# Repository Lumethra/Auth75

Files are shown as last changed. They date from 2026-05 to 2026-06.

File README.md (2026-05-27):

# Auth 75

## What is this? 

This is a 75% keyboard with a fingerprint sensor. What? A fingerprint sensor in a keyboard? Yes, you've heard it right! This keyboard includes a working fingerprint sensor. But how does it work? Aren't fingerprint sensors tied to motherboards? Continue reading, to get an answer to this question. 

### Features: 
  - Keycool84 layout (modified)
  - Raspberry Pi Pico 2W
    - ZMK (not tested)
    - LiPo battery
    - Battery charger
  - Rotary Encoder Switch (EC11)
  - USB Hub (SL2.1)
    - 1 USB-C upstream
    - 2 USB-C downstreams
    - 1 notched FPC-connector (fingerprint sensor)
    - 1 USB-C to connect to the Pico

---

## Why? 

I always wanted a good keyboard with a working fingerprint sensor, because my password is always too long and I am used to the one on my laptop. Why not just use the one on my laptop? Because I want to close my laptop lid while using a monitor. The second reason is that the one on my laptop doesnt work on Linux, so I wanted to make compatible with my main OS. 

---

## How? 

I did some research and found out that the Framework 13 Fingerprint Reader isnt tied to their motherboard, unlike Lenovo or Dell. I also found a [Framework-Community-Post](https://community.frame.work/t/framework-fingerprint-scanner-for-a-desktop-pc/29845), where the people managed to use the sensor via USB-C. They also found out that the D+ and D- pins are inverted. A huge thank you to these guys. After buying the sensor and testing its functionalty at home, I decided on using a USB-Hub to have the fingerprint reader and the keyboard MCU in on connector. Frameworks support also helped me out with the fingerprint sensor datasheet. And now I've got a 75% keyboard with a working fingerprint sensor. 

---

## Renders

| PCB with Components | 
| --- |
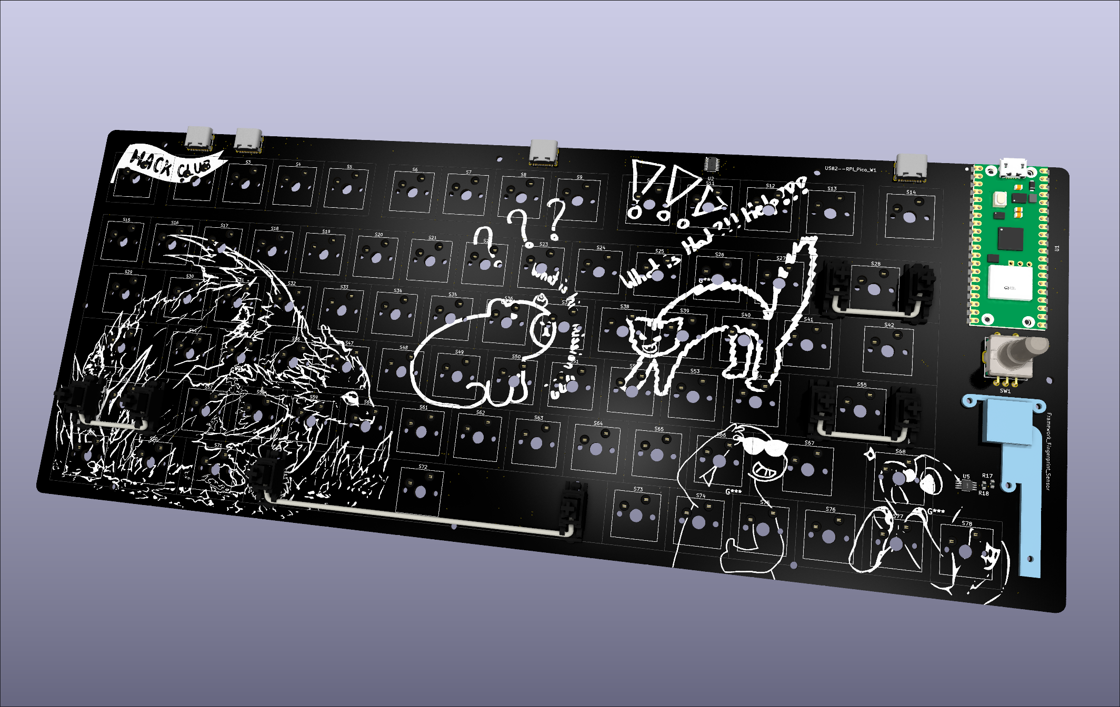
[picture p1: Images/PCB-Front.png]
Auth75 Front with Components
|  |
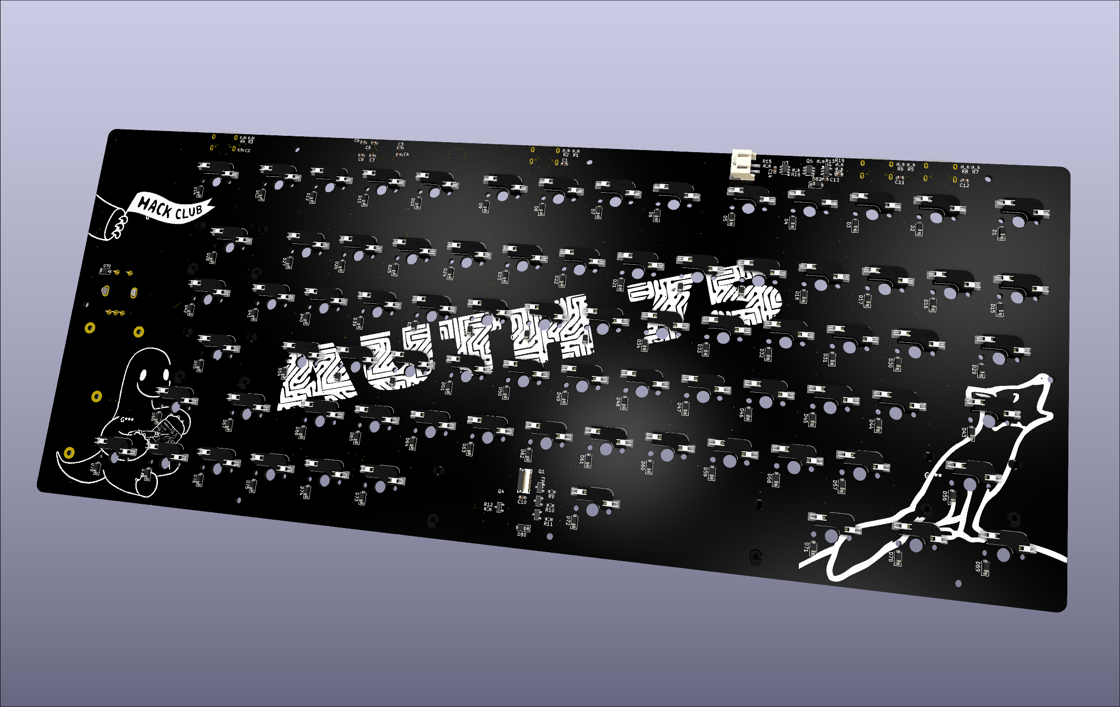
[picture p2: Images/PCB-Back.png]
Auth75 Back with Components
|  |

| PCB without Components |
| --- |
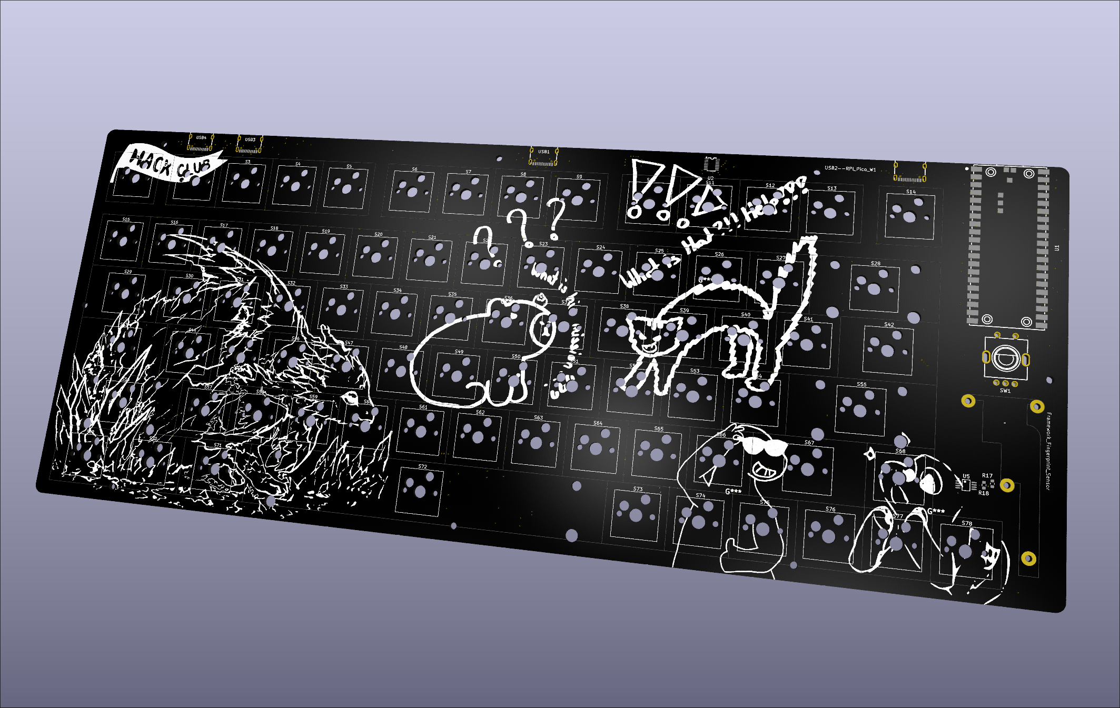
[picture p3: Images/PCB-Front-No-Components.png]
Auth75 Front without Components
|  |
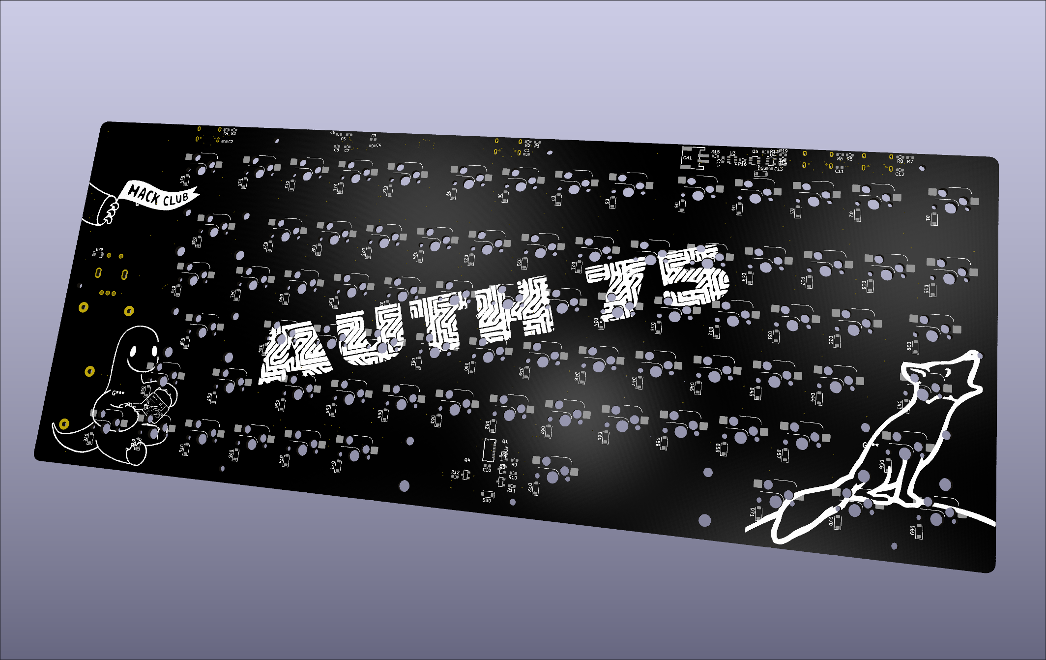
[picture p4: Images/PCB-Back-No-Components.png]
Auth75 Back without Compoenents
|  |

| Case |
| --- |
| Auth75 Case |
| Thank you Chroma for making this wonderful case |
| The case source files are [here](https://cad.onshape.com/documents/94c98908253eab7c65b6f4cc/w/cb3c129046b9b5460a1f53f5/e/8f22757c89f8236cf1eb1f99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) |

---

## PCB + Schematics

| Schematics |
| --- |
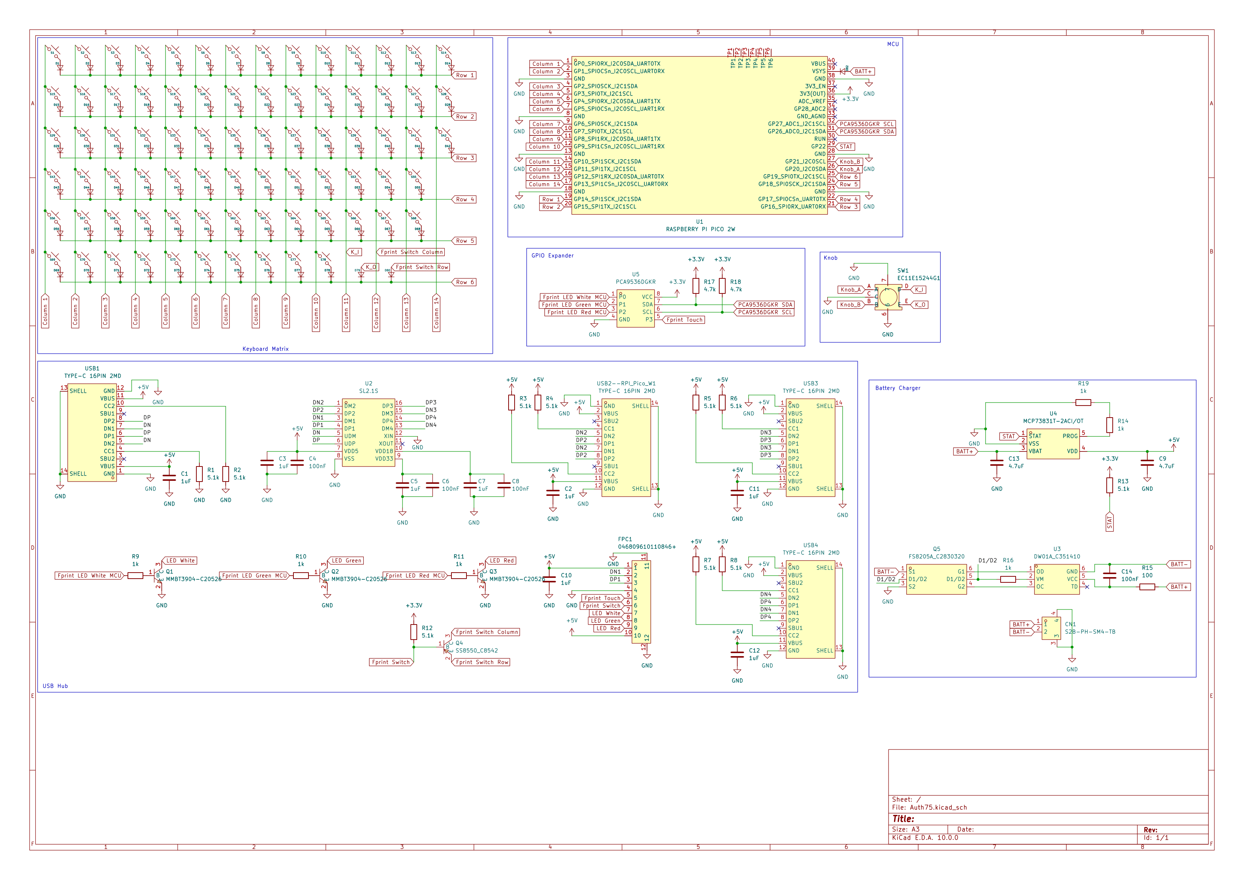
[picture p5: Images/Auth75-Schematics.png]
Auth75-PCB
|  |

| PCB |
| --- |
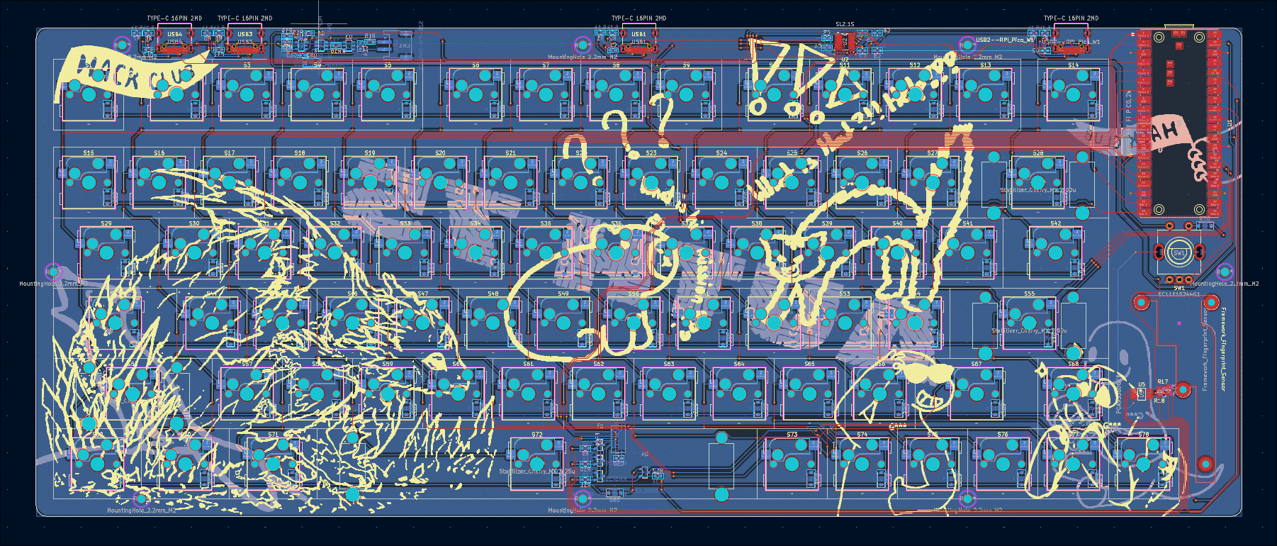
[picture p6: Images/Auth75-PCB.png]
Auth75-Schematics
|  |

---
<details>
  <summary>
    <h2>Zine</h2> 
  </summary>

| Zine |
| --- |
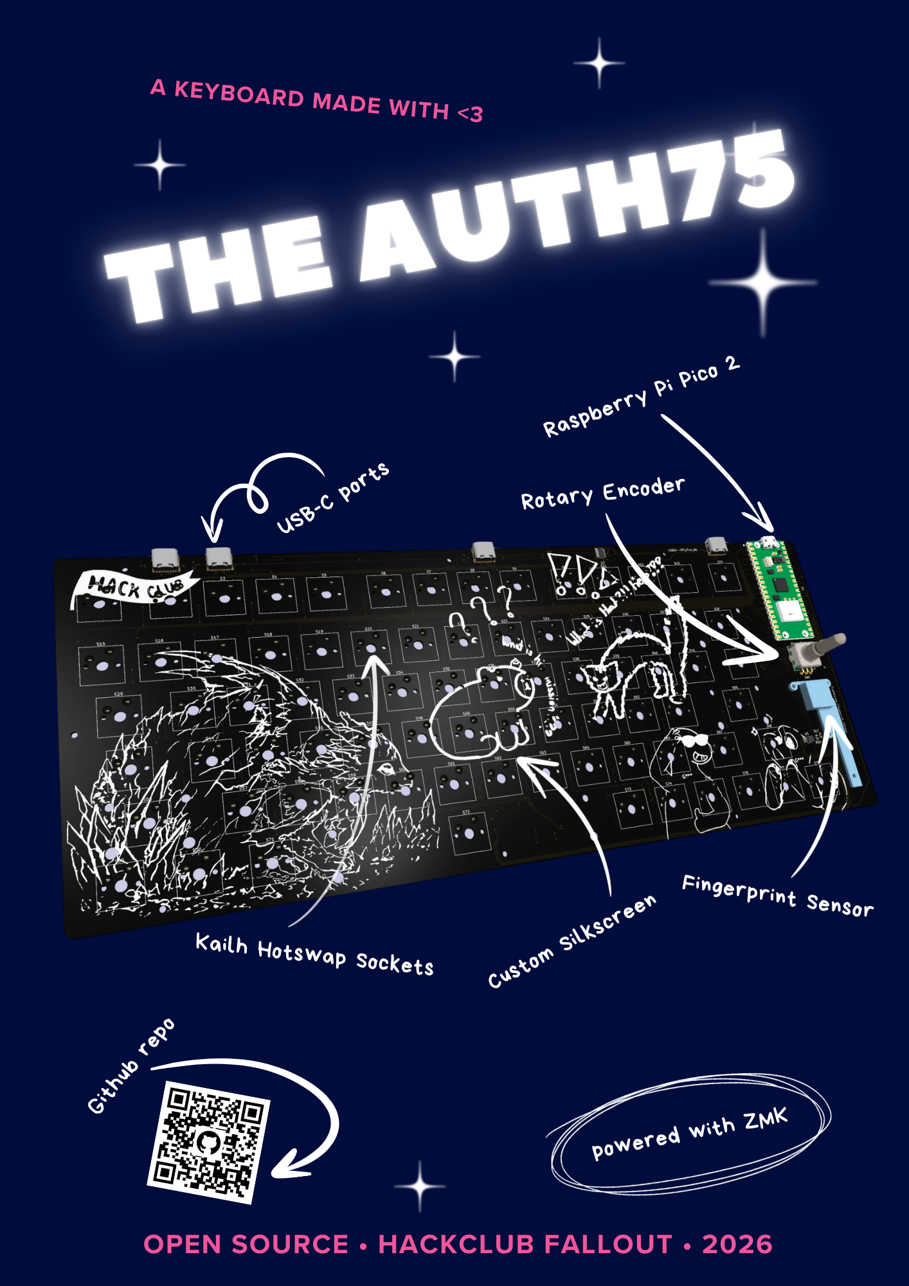
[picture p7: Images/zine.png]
Auth75-Zine
|  |

---
</details>

## BOM

| Part | Purpose | Cost | Quantity | Total Cost | LCSC/JLCPCB Number | Link |
| --- | --- | --- | --- | --- | --- | --- |
| PCB | connecting every component | ~ | 1 (5) | $22.60 | ~ | [JLCPCB](https://jlcpcb.com/) |
| Pico 2W | main MCU (handeling software) | ~$7 | 1 | $7 | C42394205 (JLCPCB) | [Raspberry Pi](https://www.raspberrypi.com/products/raspberry-pi-pico-2/) |
| Kailh Hotswap Sockets | holding the switches to the PCB without soldering | $0.1183 | 78 | ~$9 | C2803348 | [JLCPCB](https://jlcpcb.com/partdetail/C2803348) |
| Kailh (Cocoa) Switches | the switches you can press | $0 (comes with a Rainy75) | 78 | $0 (already owned) | ~ | ~ |
| Keycaps | goes onto the switches for better look and feel | $0 (3d printing ABS) | 78 | $0 (3d printed) | ~ | ~ |
| EC11 Rotary Encoder Switch | goes uii and click click | $2.22 | 1 | $2.22 | C370970 | [JLCPCB](https://jlcpcb.com/partdetail/C370970) / [Amazon](https://www.amazon.de/-/en/RUNCCI-YUN-Potentiometer-Automotive-Electronics-Multimedia/dp/B09SG3HF9N) |
| Fingerprint Reader Kit | recognize your finger | $29.00 | 1 | $29.00 | ~ | [Framework](https://frame.work/products/fingerprint-reader-kit?v=FRANTD0001) |
| KYOCERA AVX FPC Connector | connect the fingerprint sensor | $0.3775 | 1 | $0.3775 | C5464531 | [JLCPCB](https://jlcpcb.com/partdetail/C5464531) |
| USB-C connector | connect to laptop | $0.0740 | 4 | $0.296 | C2765186 | [JLCPCB](https://jlcpcb.com/partdetail/C2765186) |
| PCA9536DGKR | I2C GPIO expander (more GPIO pins, yeeee) | $1.2053 | 1 | $1.2053 | C2649389 | [JLCPCB](https://jlcpcb.com/partdetail/C2649389) |
| SL2.1s | USB Hub core component | $0.2258 | 1 | $0.2258 | C2684433 | [JLCPCB](https://jlcpcb.com/partdetail/C2684433) |
| MMBT3904 | letting the Pi control the LEDs on the sensor | $0.0095 | 3 | $0.0285 | C20526 | [JLCPCB](https://jlcpcb.com/partdetail/C20526) |
| SS8550 Y2 | implementing the sensor switch into the matrix | $0.0134 | 1 | $0.0134 | C8542 | [JLCPCB](https://jlcpcb.com/partdetail/C8542) |
| MCP73831T-2ACI/OT | battery charger | $0.7585 | 1 | $0.7585 | C424093 | [JLCPCB](https://jlcpcb.com/partdetail/C424093) |
| DW01A | battery protector | $0.0426 | 1 | $0.0426 | C351410 | [JLCPCB](https://jlcpcb.com/partdetail/C351410) |
| FS8205A | mosfet for protector | $0.0470 | 1 | $0.0470 | C2830320 | [JLCPCB](https://jlcpcb.com/partdetail/C2830320) |
| S2B-PH-SM4-TB | connector for battery | $0.2014 | 1 | $0.2014 | C295747 | [JLCPCB](https://jlcpcb.com/partdetail/C295747) |
| Resistors | prevent things go boom | ~$0.0016 | 19 | ~$0.0304 | C23186, C21190, C22775, C23162 | [C23186](https://jlcpcb.com/partdetail/C23186) / [C21190](https://jlcpcb.com/partdetail/C21190) / [C22775](https://jlcpcb.com/partdetail/C22775) / [C23162](https://jlcpcb.com/partdetail/C23162) |
| Diodes | prevent voltage from backflowing | $0.0117 | 82 | ~$0.9594 | C81598 | [JLCPCB](https://jlcpcb.com/partdetail/C81598) |
| Capacitors | smooth out the power | $0.0032 - $0.0110 | 14 | ~$0.0956 | C15849, C19666, C14663 | [C15849](https://jlcpcb.com/partdetail/C15849) / [C19666](https://jlcpcb.com/partdetail/C19666) / [C14663](https://jlcpcb.com/partdetail/C14663) |

> the prices can vary depending on the provider <br>
> you can find the JLCPCB parts on [LCSC](https://lcsc.com/) too (exept the PCB and the Pico) <br>
> note: u could solder a pico 2 on there instead, cause its physically the same

---

## Contribute

Want to make it better? Found some bugs? Feel free to open a PR (pull request) and lets make the project better. ^_^
> the libraries are all imported with [easyeda2kicad](https://github.com/uPesy/easyeda2kicad.py) and [kiswitch](https://github.com/kiswitch/kiswitch)

---

## Thank you

A huge thank you to all these guys helping me out with my project. <br>
[@eggsplats](https://github.com/geg-tech), [@Kai Pereira](https://github.com/KaiPereira), [@Aadit Bhambri](https://github.com/abinnovator), [@technical_.](https://github.com/techn1-cal) and [@Tanuki](https://github.com/TaniWanKenobi) for helping out on my way and inspiring me with their passion and projects. <br>
Another thank you to my sister (for **some** of the art), the Framework support (for the datasheet of the sensor), the guys in the [Framework-Community-Post](https://community.frame.work/t/framework-fingerprint-scanner-for-a-desktop-pc/29845) (for the functionality of the sensor), my [friend](https://github.com/Chroma165) (for the case and 3d model of the fingerprint sensor) and my [other friend](https://github.com/Leonhoch5) (for the emotional support)
> Thank you guys <3

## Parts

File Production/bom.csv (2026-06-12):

Name | Designator | Footprint | Quantity | Value | Price | LCSC Part # | Purchase Link
Capacitors 1uF | C1, C10, C11, C12, C2, C3, C5, C7 | 0603 | 8 | 1uF | $0.0032 | C15849 | https://jlcpcb.com/partdetail/C15849
Capacitors 4.7uF | C13, C9 | 0603 | 2 | 4.7uF | $0.0110 | C19666 | https://jlcpcb.com/partdetail/C19666
Capacitors 100nF | C14, C4, C6, C8 | 0603 | 4 | 100nF | $0.0032 | C14663 | https://jlcpcb.com/partdetail/C14663
S2B-PH-SM4-TB | CN1 | CONN-SMD_P2.00_S2B-PH-SM4-TB-LF-SN | 1 | S2B-PH-SM4-TB | $0.2014 | C295747 | https://jlcpcb.com/partdetail/C295747
Diodes | D1, D10, D11, D12, D13, D14, D15, D16, D17, D18, D19, D2, D20, D21, D22, D23, D24, D25, D26, D27, D28, D29, D3, D30, D31, D32, D33, D34, D35, D36, D37, D38, D39, D4, D40, D41, D42, D43, D44, D45, D46, D47, D48, D49, D5, D50, D51, D52, D53, D54, D55, D56, D57, D58, D59, D6, D60, D61, D62, D63, D64, D65, D66, D67, D68, D69, D7, D70, D71, D72, D73, D74, D75, D76, D77, D78, D79, D8, D80, D82, D9 | D_SOD-123 | 81 | ~ | $0.0117 | C81598 | https://jlcpcb.com/partdetail/C81598
KYOCERA AVX FPC Connector | FPC1 | CONN-SMD_10P-P0.50_046809610110846 | 1 | 046809610110846+ | $0.3775 | C5464531 | https://jlcpcb.com/partdetail/C5464531
MMBT3904 | Q1, Q2, Q3 | SOT-23-3_L2.9-W1.3-P1.90-LS2.4-BR | 3 | MMBT3904-C20526 | $0.0095 | C20526 | https://jlcpcb.com/partdetail/C20526
SS8550 Y2 | Q4 | SOT-23-3_L2.9-W1.3-P1.90-LS2.4-BR | 1 | SS8550_C8542 | $0.0134 | C8542 | https://jlcpcb.com/partdetail/C8542
FS8205A | Q5 | SOT-23-6_L2.9-W1.6-P0.95-LS2.8-BR | 1 | FS8205A_C2830320 | $0.0470 | C2830320 | https://jlcpcb.com/partdetail/C2830320
Resistors 5.1k | R1, R12, R13, R2 | 0603 | 4 | 5.1k | $0.0016 | C23186 | https://jlcpcb.com/partdetail/C23186
Resistors 56k | R3, R4, R5, R6, R7, R8 | 0603 | 6 | 56k | $0.0016 | C23206 | https://jlcpcb.com/partdetail/C23206
Resistors 1k | R10, R11, R14, R16, R19, R9 | 0603 | 6 | 1k | $0.0016 | C21190 | https://jlcpcb.com/partdetail/C21190
Resistors 100 | R15 | 0603 | 1 | 100 | $0.0016 | C22775 | https://jlcpcb.com/partdetail/C22775
Resistors 4.7k | R17, R18 | 0603 | 2 | 4.7k | $0.0016 | C23162 | https://jlcpcb.com/partdetail/C23162
Kailh Hotswap Sockets | S1, S10, S11, S12, S13, S14, S15, S16, S17, S18, S19, S2, S20, S21, S22, S23, S24, S25, S26, S27, S28, S29, S3, S30, S31, S32, S33, S34, S35, S36, S37, S38, S39, S4, S40, S41, S42, S43, S44, S45, S46, S47, S48, S49, S5, S50, S51, S52, S53, S54, S55, S56, S57, S58, S59, S6, S60, S61, S62, S63, S64, S65, S66, S67, S68, S69, S7, S70, S71, S72, S73, S74, S75, S76, S77, S78, S8, S9 | SW_Hotswap_Kailh_MX | 78 | ~ | $0.1183 | C2803348 | https://jlcpcb.com/partdetail/C2803348
Raspberry Pi Pico 2W | U1 | COMM-SMD_L51.0-W21.0-P2.54_PICOW | 1 | RASPBERRY PI PICO 2W | ~$7 | C42394205 | https://jlcpcb.com/partdetail/C42394205
SL2.1S | U2 | SSOP-16_L4.6-W2.6-P0.53-LS4.0-BL | 1 | SL2.1S | $0.2258 | C2684433 | https://jlcpcb.com/partdetail/C2684433
DW01A | U3 | SOT-23-6_L2.9-W1.6-P0.95-LS2.8-BL | 1 | DW01A_C351410 | $0.0426 | C351410 | https://jlcpcb.com/partdetail/C351410
MCP73831T-2ACI/OT | U4 | SOT-23-5_L3.0-W1.7-P0.95-LS2.8-BL | 1 | MCP73831T-2ACI/OT | $0.7585 | C424093 | https://jlcpcb.com/partdetail/C424093
PCA9536DGKR | U5 | VSSOP-8_L3.0-W3.0-P0.65-LS4.9-BL | 1 | PCA9536DGKR | $1.2053 | C2649389 | https://jlcpcb.com/partdetail/C2649389
USB-C Connector | USB1, USB2--RPI_PICO_W1, USB3, USB4 | USB-C-SMD_TYPE-C-6PIN-2MD-073 | 4 | TYPE-C 16PIN 2MD | $0.0740 | C2765186 | https://jlcpcb.com/partdetail/C2765186

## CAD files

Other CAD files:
CAD/keyboard-PCB.step

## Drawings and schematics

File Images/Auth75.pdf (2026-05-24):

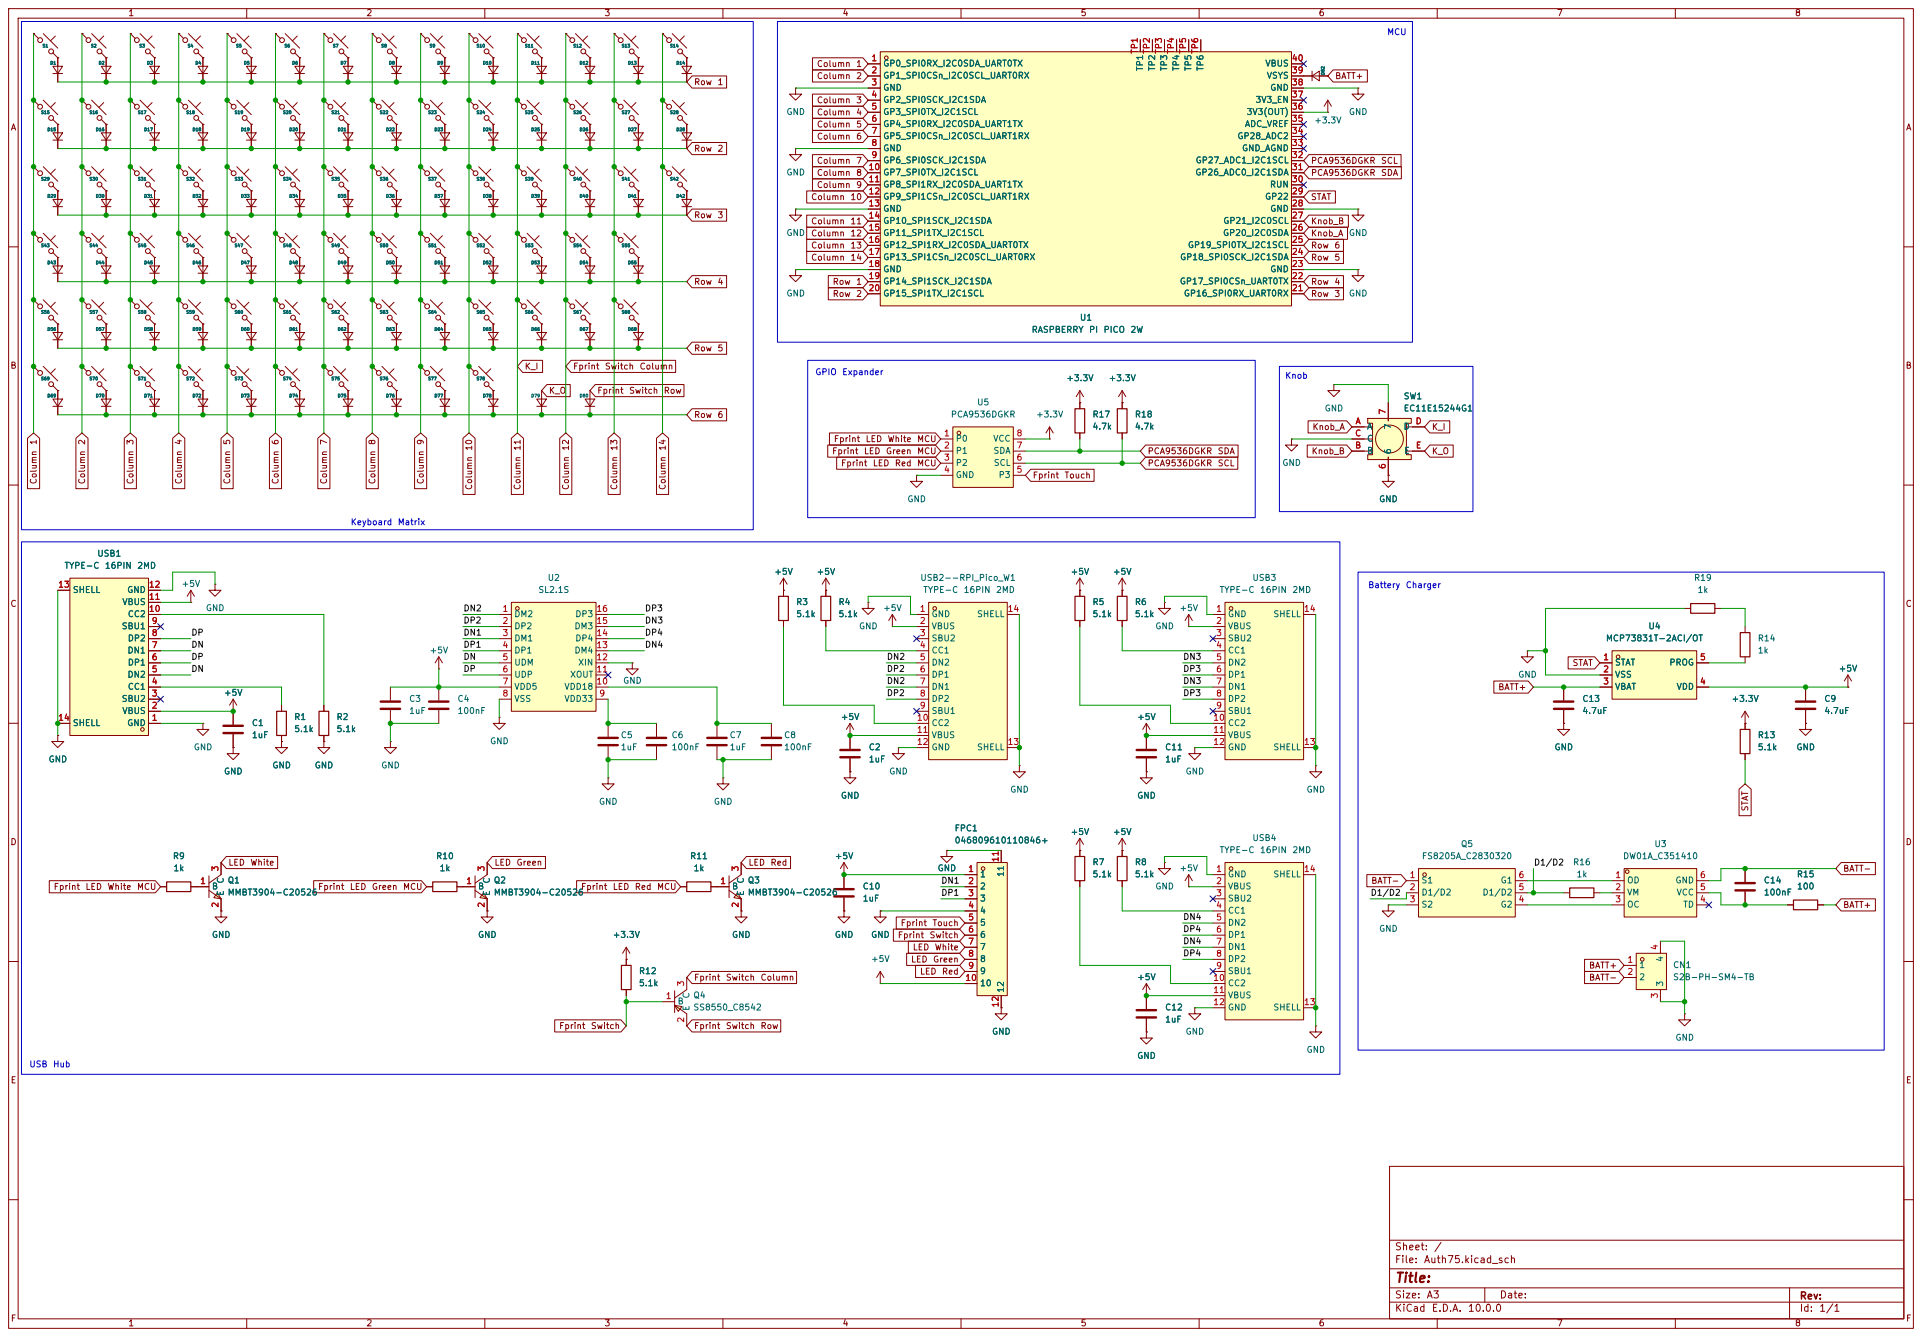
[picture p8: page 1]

MCU

Row 4 Row 3 Column 12 Column 2

S17 D16 D58 | D59 D15 S32D32 D44 | S33D33 | S20 S34 S34 S48D34 | S35D35 | D63 S36 S36 D35 D36 | S37 | S24 S24 D23 D24 S38 S38 S52D38 | S39D39 S39 D38 | S26 D54 S40 S40 D39 D40 | S27 D64 D27 D69 S41D41 D25 | Row 6 K_I Row 1 K_O S42D42

S30 | S71 | S46 D43 S72D72 | S73 | S74 | S75 D74 | S76 D74 S76 D75 D76 | C4 +5V | Fprint Switch Column

Fprint LED White MCU

BATT+ STAT Column 10 Column 7

Fprint LED Green MCU Column 13

Fprint LED Red MCU

Fprint LED Green MCU

Size: A3 | Rev: | F Date:
KiCad E.D.A. 10.0.0 | Id: 1/1

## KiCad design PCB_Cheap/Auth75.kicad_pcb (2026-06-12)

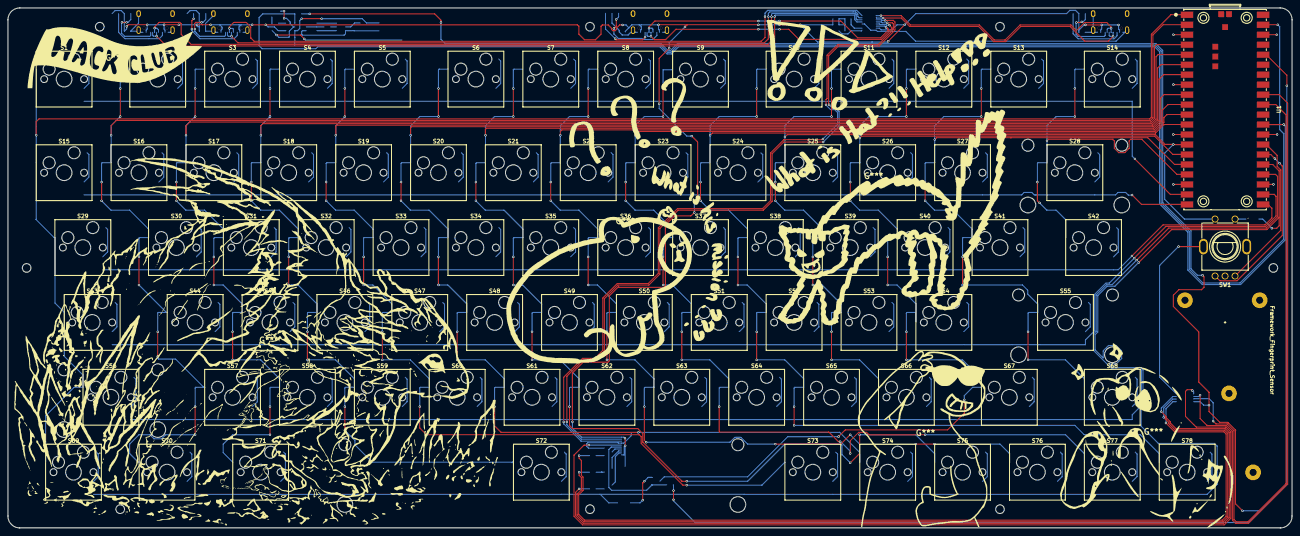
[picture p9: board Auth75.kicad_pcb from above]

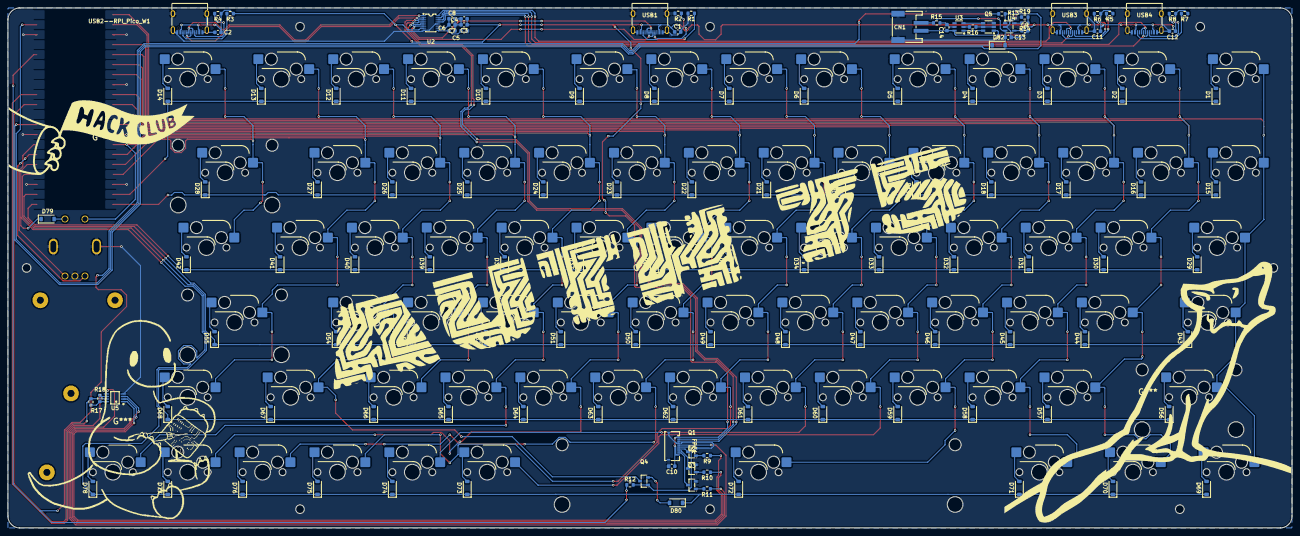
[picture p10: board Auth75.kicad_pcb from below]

Board: 2 copper layers, 326.7 x 132.3 mm, 210 parts (129 on the bottom side), 149 nets.

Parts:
C1, C2, C3, C5, C7, C10, C11, C12: 1uF; C_0603_1608Metric
C4, C6, C8, C14: 100nF; C_0603_1608Metric
C9, C13: 4.7uF; C_0603_1608Metric
CN1: S2B-PH-SM4-TB; CONN-SMD_P2.00_S2B-PH-SM4-TB-LF-SN
D1, D2, D3, D4, D5, D6, D7, D8, D9, D10, D11, D12, D13, D14, D15, D16, D17, D18, D19, D20, D21, D22, D23, D24, D25, D26, D27, D28, D29, D30, D31, D32, D33, D34, D35, D36, D37, D38, D39, D40, D41, D42, D43, D44, D45, D46, D47, D48, D49, D50, D51, D52, D53, D54, D55, D56, D57, D58, D59, D60, D61, D62, D63, D64, D65, D66, D67, D68, D69, D70, D71, D72, D73, D74, D75, D76, D77, D78, D79, D80, D82: D_SOD-123
FPC1: 046809610110846+; CONN-SMD_10P-P0.50_046809610110846
Framework_Fingerprint_Sensor: Untitled; Framework Fingerprint Sensor
Q1, Q2, Q3: MMBT3904-C20526; SOT-23-3_L2.9-W1.3-P1.90-LS2.4-BR
Q4: SS8550_C8542; SOT-23-3_L2.9-W1.3-P1.90-LS2.4-BR
Q5: FS8205A_C2830320; SOT-23-6_L2.9-W1.6-P0.95-LS2.8-BR
R1, R2, R12, R13: 5.1k; R_0603_1608Metric
R3, R4, R5, R6, R7, R8: 56k; R_0603_1608Metric
R9, R10, R11, R14, R16, R19: 1k; R_0603_1608Metric
R15: 100; R_0603_1608Metric
R17, R18: 4.7k; R_0603_1608Metric
S1, S2, S3, S4, S5, S6, S7, S8, S9, S10, S11, S12, S13, S14, S15, S16, S17, S18, S19, S20, S21, S22, S23, S24, S25, S26, S27, S28, S29, S30, S31, S32, S33, S34, S35, S36, S37, S38, S39, S40, S41, S42, S43, S44, S45, S46, S47, S48, S49, S50, S51, S52, S53, S54, S55, S56, S57, S58, S59, S60, S61, S62, S63, S64, S65, S66, S67, S68, S69, S70, S71, S72, S73, S74, S75, S76, S77, S78: SW_Hotswap_Kailh_MX
SW1: EC11E15244G1; SW-TH_EC11E15244G1
U1: RASPBERRY PI PICO 2W; COMM-SMD_L51.0-W21.0-P2.54_PICOW
U2: SL2.1S; SSOP-16_L4.6-W2.6-P0.53-LS4.0-BL
U3: DW01A_C351410; SOT-23-6_L2.9-W1.6-P0.95-LS2.8-BL
U4: MCP73831T-2ACI/OT; SOT-23-5_L3.0-W1.7-P0.95-LS2.8-BL
U5: PCA9536DGKR; VSSOP-8_L3.0-W3.0-P0.65-LS4.9-BL
USB1, USB2--RPI_Pico_W1, USB3, USB4: TYPE-C 16PIN 2MD; USB-C-SMD_TYPE-C-6PIN-2MD-073

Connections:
+3.3V: R12.1, R13.1, R17.2, R18.2, U1.36 (3V3(OUT)), U5.8 (VCC)
+5V: C1.1, C2.1, C3.1, C4.1, C9.1, C10.1, C11.1, C12.1, FPC1.1, FPC1.10, R3.1, R4.1, R5.1, R6.1, R7.1, R8.1, U2.7 (VDD5), U4.4 (VDD), USB1.2 (VBUS), USB1.11 (VBUS), USB2--RPI_Pico_W1.2 (VBUS), USB2--RPI_Pico_W1.11 (VBUS), USB3.2 (VBUS), USB3.11 (VBUS), USB4.2 (VBUS), USB4.11 (VBUS)
/D1/D2: Q5.2 (D1/D2), Q5.5 (D1/D2), R16.1
/DN: U2.5 (UDM), USB1.5 (DN2), USB1.7 (DN1)
/DN1: FPC1.2, U2.3 (DM1)
/DN2: U2.1 (DM2), USB2--RPI_Pico_W1.5 (DN2), USB2--RPI_Pico_W1.7 (DN1)
/DN3: U2.15 (DM3), USB3.5 (DN2), USB3.7 (DN1)
/DN4: U2.13 (DM4), USB4.5 (DN2), USB4.7 (DN1)
/DP: U2.6 (UDP), USB1.6 (DP1), USB1.8 (DP2)
/DP1: FPC1.3, U2.4 (DP1)
/DP2: U2.2 (DP2), USB2--RPI_Pico_W1.6 (DP1), USB2--RPI_Pico_W1.8 (DP2)
/DP3: U2.16 (DP3), USB3.6 (DP1), USB3.8 (DP2)
/DP4: U2.14 (DP4), USB4.6 (DP1), USB4.8 (DP2)
BATT+: C13.1, CN1.1, D82.2 (A), R15.2, U4.3 (VBAT)
BATT-: C14.1, CN1.2, Q5.1 (S1), U3.6 (GND)
Column 1: S1.1, S15.1, S29.1, S43.1, S56.1, S69.1, U1.1 (GP0_SPI0RX_I2C0SDA_UART0TX)
Column 2: S2.1, S16.1, S30.1, S44.1, S57.1, S70.1, U1.2 (GP1_SPI0CSn_I2C0SCL_UART0RX)
Column 3: S3.1, S17.1, S31.1, S45.1, S58.1, S71.1, U1.4 (GP2_SPI0SCK_I2C1SDA)
Column 4: S4.1, S18.1, S32.1, S46.1, S59.1, S72.1, U1.5 (GP3_SPI0TX_I2C1SCL)
Column 5: S5.1, S19.1, S33.1, S47.1, S60.1, S73.1, U1.6 (GP4_SPI0RX_I2C0SDA_UART1TX)
Column 6: S6.1, S20.1, S34.1, S48.1, S61.1, S74.1, U1.7 (GP5_SPI0CSn_I2C0SCL_UART1RX)
Column 7: S7.1, S21.1, S35.1, S49.1, S62.1, S75.1, U1.9 (GP6_SPI0SCK_I2C1SDA)
Column 8: S8.1, S22.1, S36.1, S50.1, S63.1, S76.1, U1.10 (GP7_SPI0TX_I2C1SCL)
Column 9: S9.1, S23.1, S37.1, S51.1, S64.1, S77.1, U1.11 (GP8_SPI1RX_I2C0SDA_UART1TX)
Column 10: S10.1, S24.1, S38.1, S52.1, S65.1, S78.1, U1.12 (GP9_SPI1CSn_I2C0SCL_UART1RX)
Column 11: S11.1, S25.1, S39.1, S53.1, S66.1, SW1.D, U1.14 (GP10_SPI1SCK_I2C1SDA)
Column 12: Q4.3 (C), S12.1, S26.1, S40.1, S54.1, S67.1, U1.15 (GP11_SPI1TX_I2C1SCL)
Column 13: S13.1, S27.1, S41.1, S55.1, S68.1, U1.16 (GP12_SPI1RX_I2C0SDA_UART0TX)
Column 14: S14.1, S28.1, S42.1, U1.17 (GP13_SPI1CSn_I2C0SCL_UART0RX)
Fprint LED Green MCU: R10.1, U5.2 (P1)
Fprint LED Red MCU: R11.1, U5.3 (P2)
Fprint LED White MCU: R9.1, U5.1 (P0)
Fprint Switch: FPC1.6, Q4.1 (B), R12.2
Fprint Switch Row: D80.2 (A), Q4.2 (E)
Fprint Touch: FPC1.5, U5.5 (P3)
GND: C1.2, C2.2, C3.2, C4.2, C5.2, C6.2, C7.2, C8.2, C9.2, C10.2, C11.2, C12.2, C13.2, CN1.3, CN1.4, FPC1.4, FPC1.11, FPC1.12, Q1.2 (E), Q2.2 (E), Q3.2 (E), Q5.3 (S2), R1.2, R2.2, R19.1, SW1.6, SW1.7, SW1.C, U1.3 (GND), U1.8 (GND), U1.13 (GND), U1.18 (GND), U1.23 (GND), U1.28 (GND), U1.38 (GND), U2.8 (VSS), U2.12 (XIN), U4.2 (VSS), U5.4 (GND), USB1.1 (GND), USB1.12 (GND), USB1.13 (SHELL), USB1.14 (SHELL), USB2--RPI_Pico_W1.1 (GND), USB2--RPI_Pico_W1.12 (GND), USB2--RPI_Pico_W1.13 (SHELL), USB2--RPI_Pico_W1.14 (SHELL), USB3.1 (GND), USB3.12 (GND), USB3.13 (SHELL), USB3.14 (SHELL), USB4.1 (GND), USB4.12 (GND), USB4.13 (SHELL), USB4.14 (SHELL)
K_O: D79.2 (A), SW1.E
Knob_A: SW1.A, U1.26 (GP20_I2C0SDA)
Knob_B: SW1.B, U1.27 (GP21_I2C0SCL)
LED Green: FPC1.8, Q2.3 (C)
LED Red: FPC1.9, Q3.3 (C)
LED White: FPC1.7, Q1.3 (C)
unnamed: D1.2 (A), S1.2
unnamed: D2.2 (A), S2.2
unnamed: D3.2 (A), S3.2
unnamed: D4.2 (A), S4.2
unnamed: D5.2 (A), S5.2
unnamed: D6.2 (A), S6.2
unnamed: D7.2 (A), S7.2
unnamed: D8.2 (A), S8.2
unnamed: D9.2 (A), S9.2
unnamed: D10.2 (A), S10.2
unnamed: D11.2 (A), S11.2
unnamed: D12.2 (A), S12.2
unnamed: D13.2 (A), S13.2
unnamed: D14.2 (A), S14.2
unnamed: D15.2 (A), S15.2
unnamed: D16.2 (A), S16.2
unnamed: D17.2 (A), S17.2
unnamed: D18.2 (A), S18.2
unnamed: D19.2 (A), S19.2
unnamed: D20.2 (A), S20.2
unnamed: D21.2 (A), S21.2
unnamed: D22.2 (A), S22.2
unnamed: D23.2 (A), S23.2
unnamed: D24.2 (A), S24.2
unnamed: D25.2 (A), S25.2
unnamed: D26.2 (A), S26.2
unnamed: D27.2 (A), S27.2
unnamed: D28.2 (A), S28.2
unnamed: D29.2 (A), S29.2
unnamed: D30.2 (A), S30.2
unnamed: D31.2 (A), S31.2
unnamed: D32.2 (A), S32.2
unnamed: D33.2 (A), S33.2
unnamed: D34.2 (A), S34.2
unnamed: D35.2 (A), S35.2
unnamed: D36.2 (A), S36.2
unnamed: D37.2 (A), S37.2
unnamed: D38.2 (A), S38.2
unnamed: D39.2 (A), S39.2
unnamed: D40.2 (A), S40.2
unnamed: D41.2 (A), S41.2
unnamed: D42.2 (A), S42.2
unnamed: D43.2 (A), S43.2
unnamed: D44.2 (A), S44.2
unnamed: D45.2 (A), S45.2
unnamed: D46.2 (A), S46.2
unnamed: D47.2 (A), S47.2
unnamed: D48.2 (A), S48.2
unnamed: D49.2 (A), S49.2
unnamed: D50.2 (A), S50.2
unnamed: D51.2 (A), S51.2
unnamed: D52.2 (A), S52.2
unnamed: D53.2 (A), S53.2
unnamed: D54.2 (A), S54.2
unnamed: D55.2 (A), S55.2
unnamed: D56.2 (A), S56.2
unnamed: D57.2 (A), S57.2
unnamed: D58.2 (A), S58.2
unnamed: D59.2 (A), S59.2
unnamed: D60.2 (A), S60.2
unnamed: D61.2 (A), S61.2
unnamed: D62.2 (A), S62.2
unnamed: D63.2 (A), S63.2
unnamed: D64.2 (A), S64.2
unnamed: D65.2 (A), S65.2
unnamed: D66.2 (A), S66.2
unnamed: D67.2 (A), S67.2
unnamed: D68.2 (A), S68.2
unnamed: D69.2 (A), S69.2
unnamed: D70.2 (A), S70.2
unnamed: D71.2 (A), S71.2
unnamed: D72.2 (A), S72.2
unnamed: D73.2 (A), S73.2
unnamed: D74.2 (A), S74.2
unnamed: D75.2 (A), S75.2
unnamed: D76.2 (A), S76.2
unnamed: D77.2 (A), S77.2
unnamed: D78.2 (A), S78.2
unnamed: D82.1 (K), U1.39 (VSYS)
unnamed: Q1.1 (B), R9.2
unnamed: Q2.1 (B), R10.2
unnamed: Q3.1 (B), R11.2
unnamed: Q5.6 (G1), U3.1 (OD)
unnamed: Q5.4 (G2), U3.3 (OC)
unnamed: R14.1, R19.2
unnamed: C7.1, C8.1, U2.10 (VDD18)
unnamed: C5.1, C6.1, U2.9 (VDD33)
unnamed: C14.2, R15.1, U3.5 (VCC)
unnamed: R16.2, U3.2 (VM)
unnamed: R14.2, U4.5 (PROG)
unnamed: R1.1, USB1.4 (CC1)
unnamed: R2.1, USB1.10 (CC2)
unnamed: R4.2, USB2--RPI_Pico_W1.4 (CC1)
unnamed: R3.2, USB2--RPI_Pico_W1.10 (CC2)
unnamed: R6.2, USB3.4 (CC1)
unnamed: R5.2, USB3.10 (CC2)
unnamed: R8.2, USB4.4 (CC1)
unnamed: R7.2, USB4.10 (CC2)
PCA9536DGKR SCL: R18.1, U1.32 (GP27_ADC1_I2C1SCL), U5.6 (SCL)
PCA9536DGKR SDA: R17.1, U1.31 (GP26_ADC0_I2C1SDA), U5.7 (SDA)
Row 1: D1.1 (K), D2.1 (K), D3.1 (K), D4.1 (K), D5.1 (K), D6.1 (K), D7.1 (K), D8.1 (K), D9.1 (K), D10.1 (K), D11.1 (K), D12.1 (K), D13.1 (K), D14.1 (K), U1.19 (GP14_SPI1SCK_I2C1SDA)
Row 2: D15.1 (K), D16.1 (K), D17.1 (K), D18.1 (K), D19.1 (K), D20.1 (K), D21.1 (K), D22.1 (K), D23.1 (K), D24.1 (K), D25.1 (K), D26.1 (K), D27.1 (K), D28.1 (K), U1.20 (GP15_SPI1TX_I2C1SCL)
Row 3: D29.1 (K), D30.1 (K), D31.1 (K), D32.1 (K), D33.1 (K), D34.1 (K), D35.1 (K), D36.1 (K), D37.1 (K), D38.1 (K), D39.1 (K), D40.1 (K), D41.1 (K), D42.1 (K), U1.21 (GP16_SPI0RX_UART0RX)
Row 4: D43.1 (K), D44.1 (K), D45.1 (K), D46.1 (K), D47.1 (K), D48.1 (K), D49.1 (K), D50.1 (K), D51.1 (K), D52.1 (K), D53.1 (K), D54.1 (K), D55.1 (K), U1.22 (GP17_SPI0CSn_UART0TX)
Row 5: D56.1 (K), D57.1 (K), D58.1 (K), D59.1 (K), D60.1 (K), D61.1 (K), D62.1 (K), D63.1 (K), D64.1 (K), D65.1 (K), D66.1 (K), D67.1 (K), D68.1 (K), U1.24 (GP18_SPI0SCK_I2C1SDA)
Row 6: D69.1 (K), D70.1 (K), D71.1 (K), D72.1 (K), D73.1 (K), D74.1 (K), D75.1 (K), D76.1 (K), D77.1 (K), D78.1 (K), D79.1 (K), D80.1 (K), U1.25 (GP19_SPI0TX_I2C1SCL)
STAT: R13.2, U1.29 (GP22), U4.1 (STAT)

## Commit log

2026-05-17 adding and improving lib and adding CAD
    [bom.csv, designators.csv, keyboard-PCB.step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]
2026-05-21 adding battery charger
    [Auth75.kicad_sch, bom.csv, designators.csv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]
2026-05-23 Wrap up project and adding silkscreen
    [Auth75.kicad_sch, bom.csv, designators.csv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]
2026-05-25 Finishing BOM
2026-05-25 finishing readme
    missing case design, but whatever
2026-05-25 new firmware with encoder
2026-05-26 hope this counts as links
    [BOM-4-persons.csv, bom.csv, designators.csv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]
2026-05-26 adding name
    [bom.csv]
2026-06-07 making a cheaper version
    [Auth75.kicad_pcb, Auth75.kicad_sch, positions_Cheap.csv]
2026-06-12 56k resis for pull up
    [Auth75.kicad_pcb, Auth75.kicad_sch, bom.csv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]
